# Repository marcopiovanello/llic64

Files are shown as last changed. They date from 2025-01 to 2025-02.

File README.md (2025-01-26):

Yet-Another-ControlPort-Converter for the Commodore C64



WIP!!

I'm developing yet another converter for Atari joystick based systems to USB.

What's different from other solutions?

Basically it's externally powered, which means that you can plug virtually anything and not think about drawing too much power from the system (e.g. the 100mA limit of the C64)

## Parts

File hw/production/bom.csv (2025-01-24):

Designator | Footprint | Quantity | Value | LCSC Part #
C1 | 0402 | 1 | 10n | C15195
C2 | 0603 | 1 | 100n | C14663
C200, C201, C204, C205, C206, C207, C208, C209, C210, C214, C300, C301, C302, C303, C304 | 0402 | 15 | 100n | C1525
C202, C203, C211 | 0402 | 3 | 1u | C52923
C215 | 0402 | 1 | 15p | C1548
C3 | 0603 | 1 | 1u | C15849
C4 | 0805 | 1 | 10u | C440198
D2 | D_SOD-323 | 1 | D_Schottky | C191023
D6, D7 | 0603 | 2 | RED | C2286
FB1 | 0805 | 1 | 100Ω@100MHz | C1015
J1 | USB_C_Receptacle_GCT_USB4125-xx-x_6P_TopMnt_Horizontal | 1 | USB_C_Receptacle_PowerOnly_6P | C456012
J100 | PinHeader_1x05_P2.54mm_Vertical | 1 | Conn_01x05_Pin
J2 | CONN_UJ2-AH-SMT_CUD | 1 | USB_A
J300 | DSUB-9_Female_EdgeMount_P2.77mm | 1 | DE9_Receptacle
R200, R201 | 0402 | 2 | 27R | C25092
R203, R6, R9 | 0402 | 3 | 1k | C11702
R204, R207 | 0402 | 2 | 10k
R7, R8 | 0402 | 2 | 5K1
SW1 | SW_SPST_B3U-1000P | 1 | SW_Push | C498294
U1 | Texas_DRT-3 | 1 | TPD2EUSB30 | C97502
U2 | WSON-6-1EP_2x2mm_P0.65mm_EP1x1.6mm_ThermalVias | 1 | TLV76733DRVx | C2848334
U200 | QFN-56-1EP_7x7mm_P0.4mm_EP3.2x3.2mm_ThermalVias | 1 | RP2040
U201 | Winbond_USON-8-1EP_3x2mm_P0.5mm_EP0.2x1.6mm | 1 | W25Q16JVUXIQ | C2843335
U300, U301, U302, U303, U304 | SOT-353_SC-70-5 | 5 | 74AHCT1G125
X100 | Crystal_SMD_2016-4Pin_2.0x1.6mm | 1 | ASE-12MHz | C669076

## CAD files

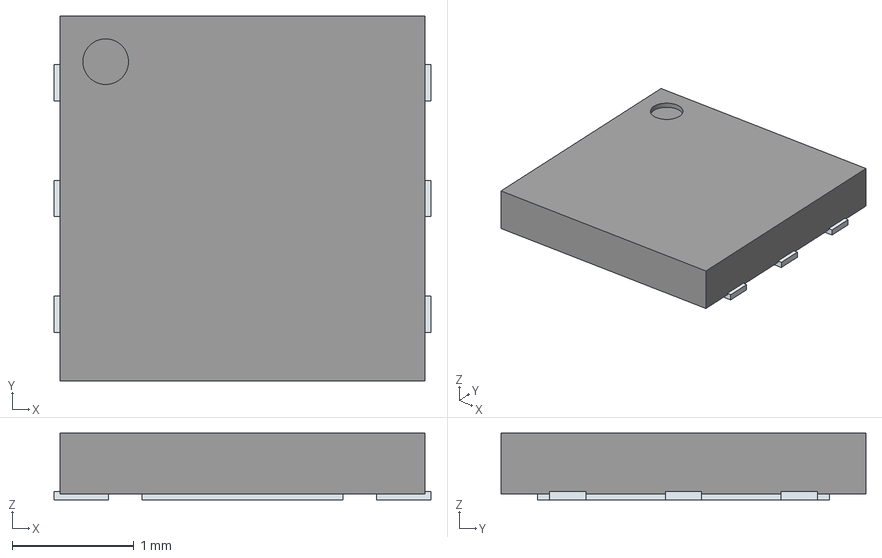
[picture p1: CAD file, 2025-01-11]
hw/NCP708MU330TAG/NCP708MU330TAG.stp
3.10 x 3.00 x 0.55 mm
ThermalPin
PinsArrayLR

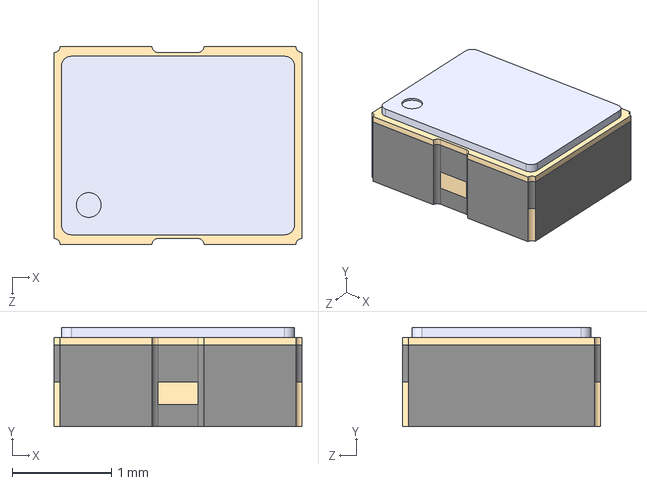
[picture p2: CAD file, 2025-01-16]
hw/OSC.STEP
2.50 x 1.00 x 2.00 mm

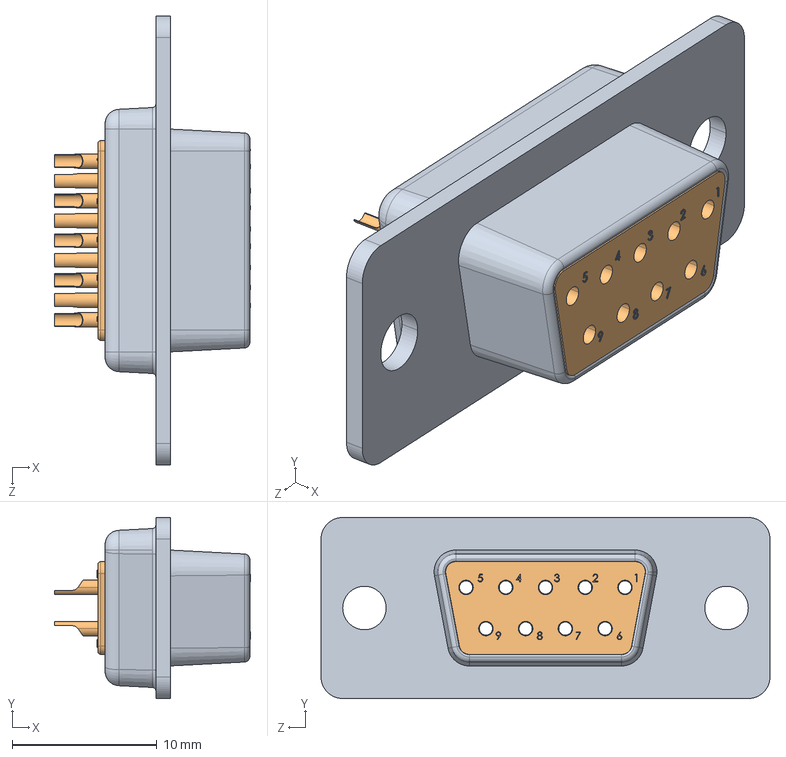
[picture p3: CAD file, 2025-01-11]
hw/DB9 female connector.STEP
13.5 x 12.5 x 31.0 mm

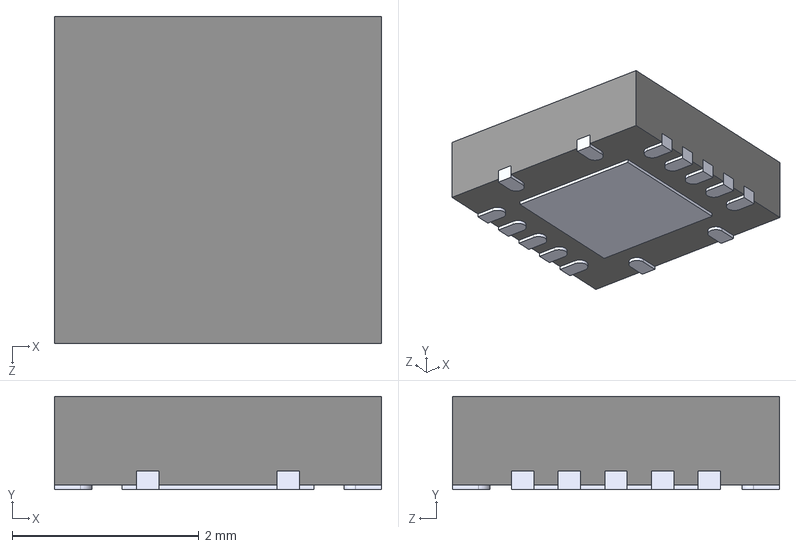
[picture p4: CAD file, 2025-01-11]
hw/SN74AHCT125RGYR.step
3.50 x 1.00 x 3.50 mm

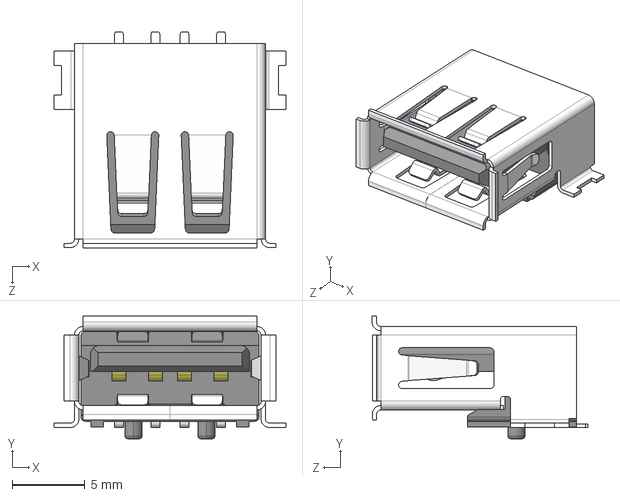
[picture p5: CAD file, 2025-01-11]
hw/UJ2-AH-4-SMT.step
15.9 x 8.40 x 14.8 mm

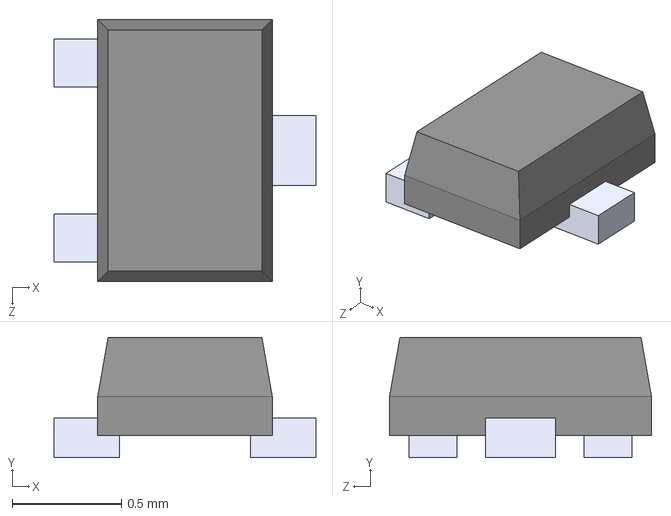
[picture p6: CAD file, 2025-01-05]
hw/SOT723.STEP
1.20 x 0.55 x 1.20 mm

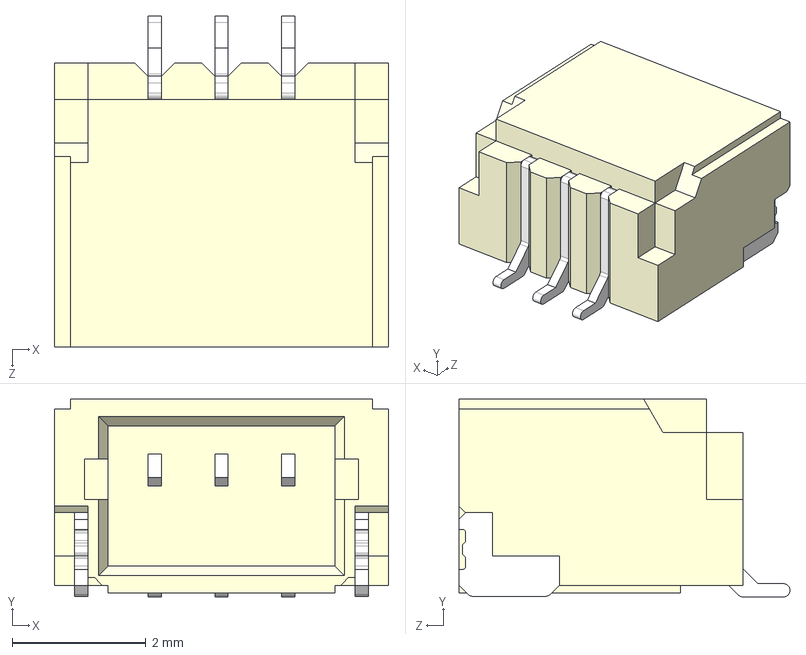
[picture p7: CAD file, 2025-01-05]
hw/SM03B-SRSS-TB(LF)(SN)--3DModel-STEP-56544.STEP
5.00 x 2.96 x 4.95 mm

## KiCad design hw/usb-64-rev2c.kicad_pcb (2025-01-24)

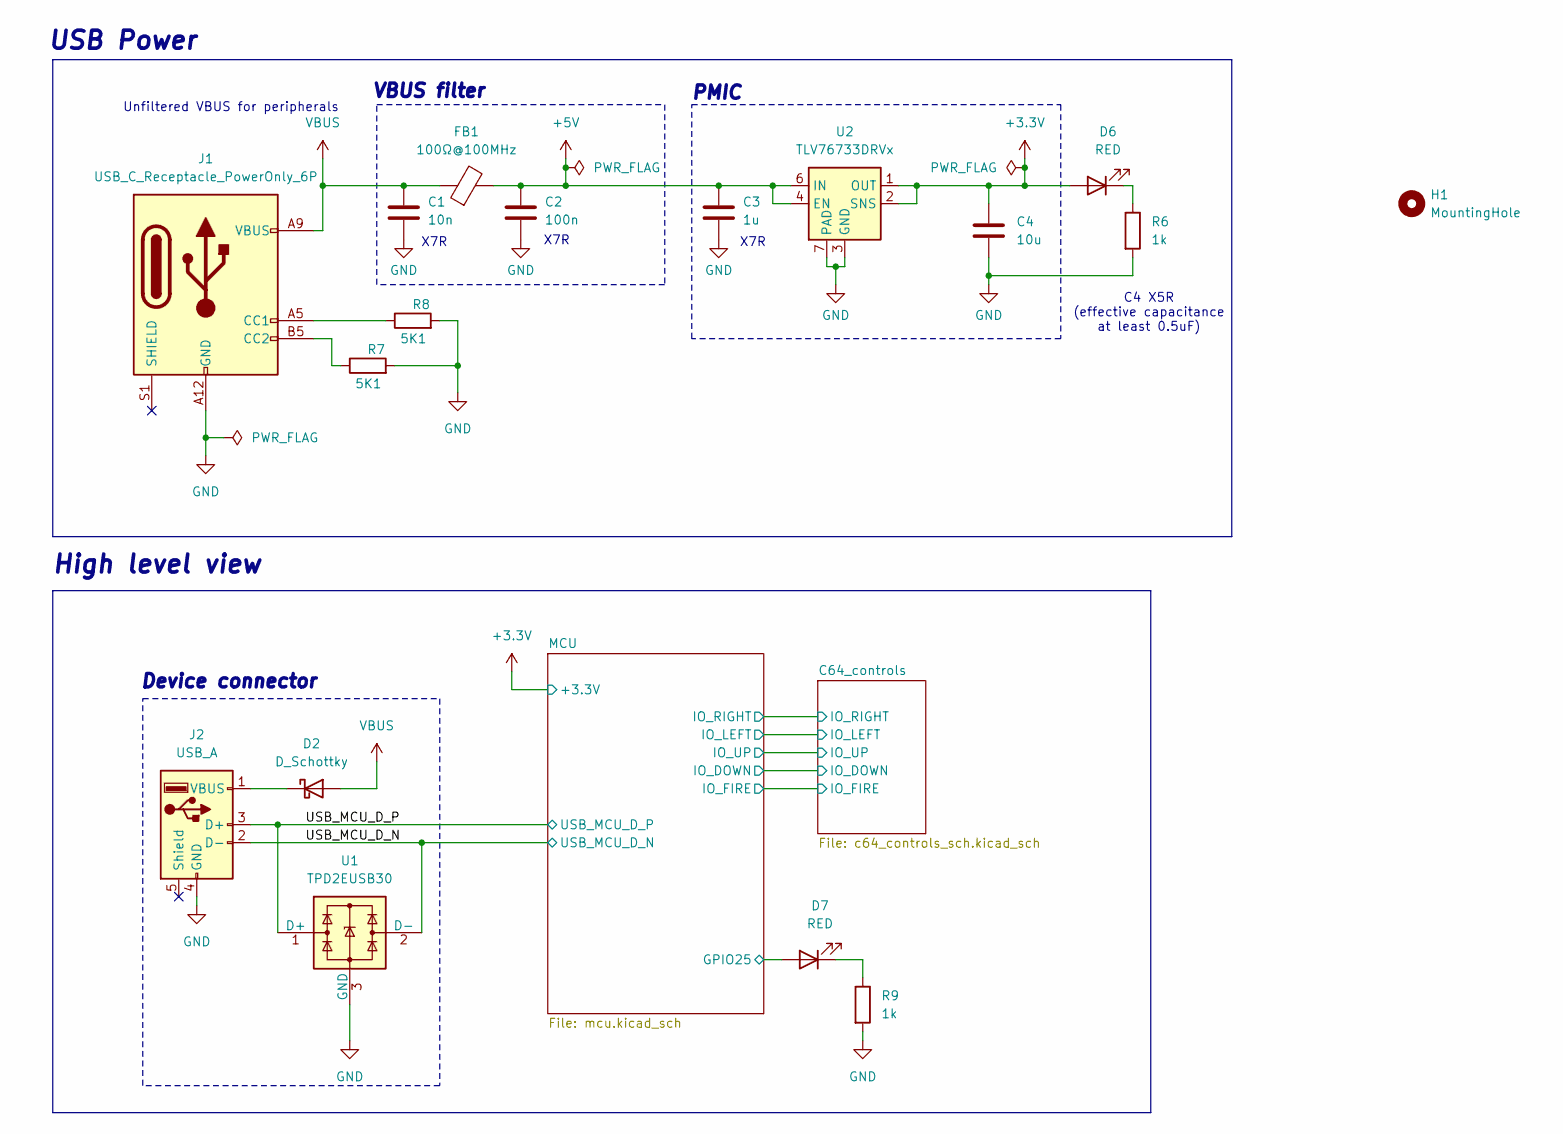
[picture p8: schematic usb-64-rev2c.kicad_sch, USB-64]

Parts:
C1: 10n; C_0402_1005Metric; LCSC Part # C15195
C2: 100n; C_0603_1608Metric; LCSC Part # C14663
C3: 1u; C_0603_1608Metric; LCSC Part # C15849
C4: 10u; C_0805_2012Metric; LCSC Part # C440198
D2: D_Schottky; D_SOD-323; LCSC Part # C191023
D6, D7: RED; LED_0603_1608Metric; LCSC Part # C2286
FB1: 100Ω@100MHz; L_0805_2012Metric; LCSC Part # C1015
H1: MountingHole; MountingHole_2.2mm_M2
J1: USB_C_Receptacle_PowerOnly_6P; USB_C_Receptacle_GCT_USB4125-xx-x_6P_TopMnt_Horizontal; LCSC Part # C456012
J2: USB_A; CONN_UJ2-AH-SMT_CUD
R6, R9: 1k; R_0402_1005Metric; LCSC Part # C11702
R7, R8: 5K1; R_0402_1005Metric
U1: TPD2EUSB30; Texas_DRT-3; LCSC Part # C97502
U2: TLV76733DRVx; WSON-6-1EP_2x2mm_P0.65mm_EP1x1.6mm_ThermalVias; LCSC Part # C2848334

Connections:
+3.3V: C4.1, D6.2 (A), U2.1 (OUT), U2.2 (SNS); also elsewhere on the board
+5V: C2.1, C3.1, FB1.2, U2.4 (EN), U2.6 (IN); also elsewhere on the board
/MCU/GPIO25: D7.2 (A); also elsewhere on the board
/USB_MCU_D_N: J2.2 (D-), U1.2 (D-); also elsewhere on the board
/USB_MCU_D_P: J2.3 (D+), U1.1 (D+); also elsewhere on the board
GND: C1.2, C2.2, C3.2, C4.2, J1.A12 (GND), J1.B12 (GND), J2.4 (GND), R6.2, R7.2, R8.2, R9.2, U1.3 (GND), U2.3 (GND), U2.5 (GND), U2.7 (PAD); also elsewhere on the board
unnamed: D2.1 (K), J2.1 (VBUS)
unnamed: D6.1 (K), R6.1
unnamed: D7.1 (K), R9.1
unnamed: J1.A5 (CC1), R8.1
unnamed: J1.B5 (CC2), R7.1
VBUS: C1.1, D2.2 (A), FB1.1, J1.A9 (VBUS), J1.B9 (VBUS)

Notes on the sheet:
PMIC
X7R
USB Power
X7R
High level view
Unfiltered VBUS for peripherals
C4 X5R (effective capacitance at least 0.5uF)
Device connector
VBUS filter

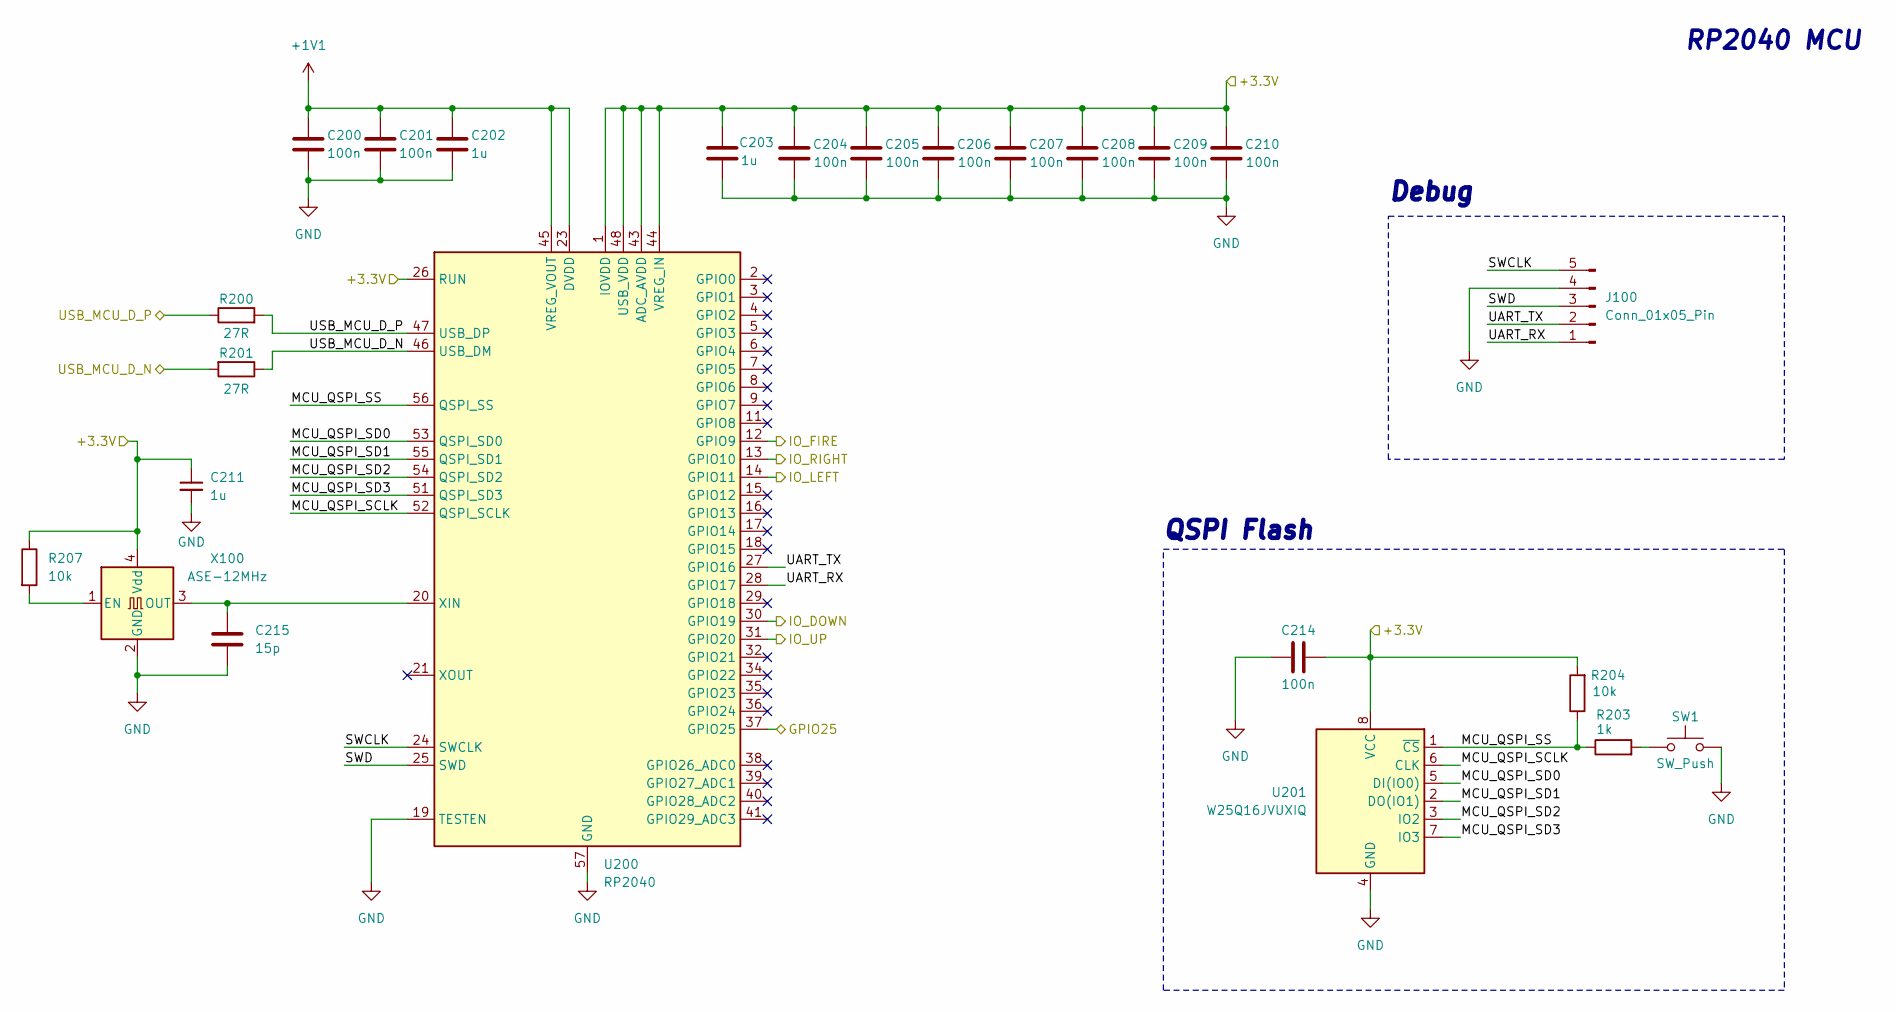
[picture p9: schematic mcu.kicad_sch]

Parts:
C200, C201, C204, C205, C206, C207, C208, C209, C210, C214: 100n; C_0402_1005Metric; LCSC Part # C1525
C202, C203, C211: 1u; C_0402_1005Metric; LCSC Part # C52923
C215: 15p; C_0402_1005Metric
J100: Conn_01x05_Pin; PinHeader_1x05_P2.54mm_Vertical
R200, R201: 27R; R_0402_1005Metric; LCSC Part # C25092
R203: 1k; R_0402_1005Metric; LCSC Part # C11702
R204, R207: 10k; R_0402_1005Metric
SW1: SW_Push; SW_SPST_B3U-1000P; LCSC Part # C498294
U200: RP2040; QFN-56-1EP_7x7mm_P0.4mm_EP3.2x3.2mm_ThermalVias
U201: W25Q16JVUXIQ; Winbond_USON-8-1EP_3x2mm_P0.5mm_EP0.2x1.6mm; LCSC Part # C2843335
X100: ASE-12MHz; Crystal_SMD_2016-4Pin_2.0x1.6mm; LCSC Part # C669076

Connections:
+1V1: C200.1, C201.1, C202.1, U200.23 (DVDD), U200.45 (VREG_VOUT), U200.50 (DVDD)
+3.3V: C203.1, C204.1, C205.1, C206.1, C207.1, C208.1, C209.1, C210.1, C211.1, C214.2, R204.2, R207.1, U200.1 (IOVDD), U200.10 (IOVDD), U200.22 (IOVDD), U200.26 (RUN), U200.33 (IOVDD), U200.42 (IOVDD), U200.43 (ADC_AVDD), U200.44 (VREG_IN), U200.48 (USB_VDD), U200.49 (IOVDD), U201.8 (VCC), X100.4 (Vdd); also elsewhere on the board
/C64_controls/IO_DOWN: U200.30 (GPIO19); also elsewhere on the board
/C64_controls/IO_FIRE: U200.12 (GPIO9); also elsewhere on the board
/C64_controls/IO_LEFT: U200.14 (GPIO11); also elsewhere on the board
/C64_controls/IO_RIGHT: U200.13 (GPIO10); also elsewhere on the board
/C64_controls/IO_UP: U200.31 (GPIO20); also elsewhere on the board
/MCU/GPIO25: U200.37 (GPIO25); also elsewhere on the board
/MCU/MCU_QSPI_SCLK: U200.52 (QSPI_SCLK), U201.6 (CLK)
/MCU/MCU_QSPI_SD0: U200.53 (QSPI_SD0), U201.5 (DI(IO0))
/MCU/MCU_QSPI_SD1: U200.55 (QSPI_SD1), U201.2 (DO(IO1))
/MCU/MCU_QSPI_SD2: U200.54 (QSPI_SD2), U201.3 (IO2)
/MCU/MCU_QSPI_SD3: U200.51 (QSPI_SD3), U201.7 (IO3)
/MCU/MCU_QSPI_SS: R203.1, R204.1, U200.56 (QSPI_SS), U201.1 (~CS)
/MCU/SWCLK: J100.5, U200.24 (SWCLK)
/MCU/SWD: J100.3, U200.25 (SWD)
/MCU/UART_RX: J100.1, U200.28 (GPIO17)
/MCU/UART_TX: J100.2, U200.27 (GPIO16)
/USB_MCU_D_N: R201.1, R201.2, U200.46 (USB_DM); also elsewhere on the board
/USB_MCU_D_P: R200.1, R200.2, U200.47 (USB_DP); also elsewhere on the board
GND: C200.2, C201.2, C202.2, C203.2, C204.2, C205.2, C206.2, C207.2, C208.2, C209.2, C210.2, C211.2, C214.1, C215.2, J100.4, SW1.2, U200.19 (TESTEN), U200.57 (GND), U201.4 (GND), X100.2 (GND); also elsewhere on the board
unnamed: R203.2, SW1.1
unnamed: C215.1, U200.20 (XIN), X100.3 (OUT)
unnamed: R207.2, X100.1 (EN)

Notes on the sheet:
Debug
RP2040 MCU
QSPI Flash

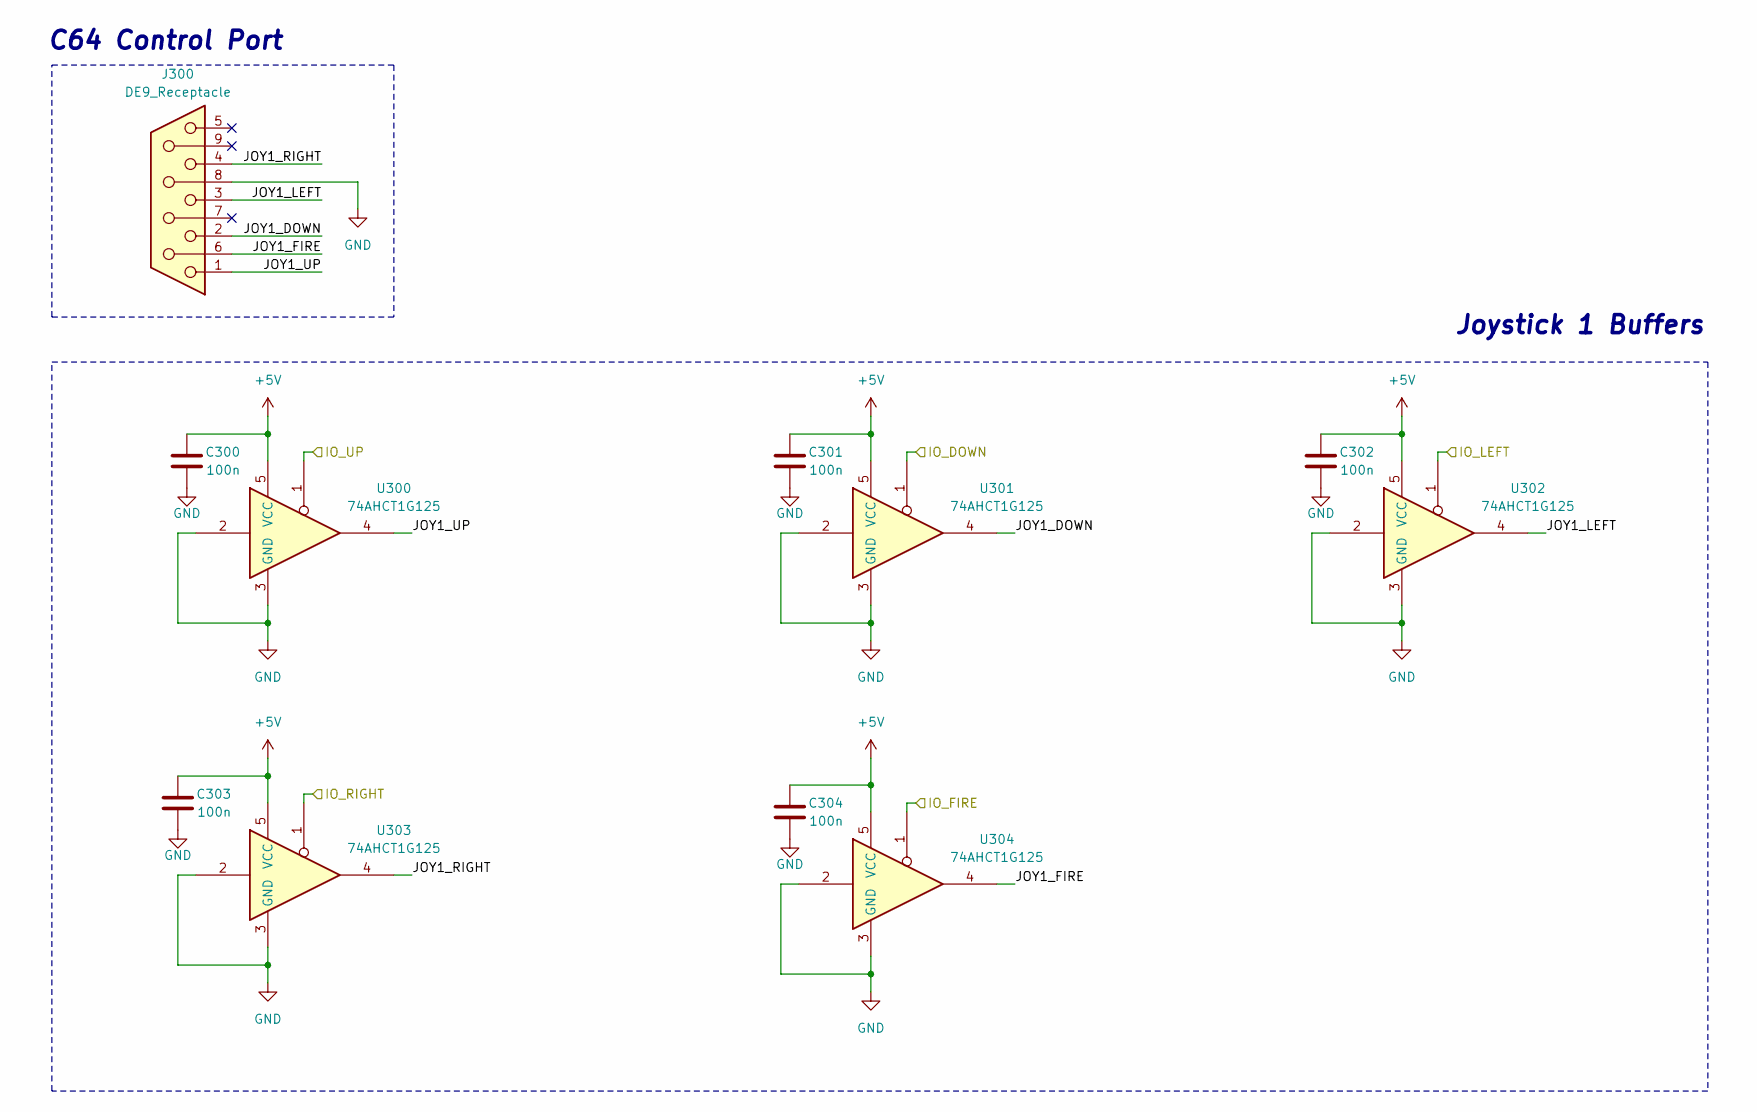
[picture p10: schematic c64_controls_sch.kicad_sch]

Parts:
C300, C301, C302, C303, C304: 100n; C_0402_1005Metric; LCSC Part # C1525
J300: DE9_Receptacle; DSUB-9_Female_EdgeMount_P2.77mm
U300, U301, U302, U303, U304: 74AHCT1G125; SOT-353_SC-70-5

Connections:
+5V: C300.1, C301.1, C302.1, C303.1, C304.1, U300.5 (VCC), U301.5 (VCC), U302.5 (VCC), U303.5 (VCC), U304.5 (VCC); also elsewhere on the board
/C64_controls/IO_DOWN: U301.1; also elsewhere on the board
/C64_controls/IO_FIRE: U304.1; also elsewhere on the board
/C64_controls/IO_LEFT: U302.1; also elsewhere on the board
/C64_controls/IO_RIGHT: U303.1; also elsewhere on the board
/C64_controls/IO_UP: U300.1; also elsewhere on the board
/C64_controls/JOY1_DOWN: J300.2, U301.4
/C64_controls/JOY1_FIRE: J300.6, U304.4
/C64_controls/JOY1_LEFT: J300.3, U302.4
/C64_controls/JOY1_RIGHT: J300.4, U303.4
/C64_controls/JOY1_UP: J300.1, U300.4
GND: C300.2, C301.2, C302.2, C303.2, C304.2, J300.8, U300.2, U300.3 (GND), U301.2, U301.3 (GND), U302.2, U302.3 (GND), U303.2, U303.3 (GND), U304.2, U304.3 (GND); also elsewhere on the board

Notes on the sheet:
C64 Control Port
Joystick 1 Buffers

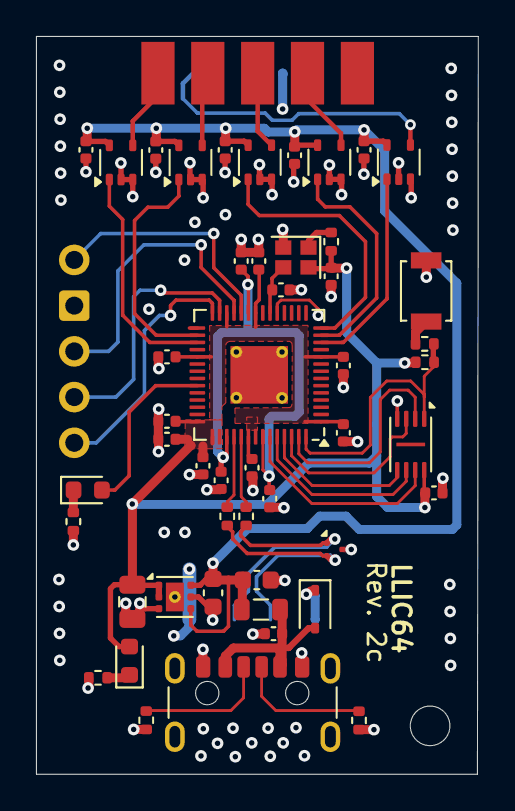
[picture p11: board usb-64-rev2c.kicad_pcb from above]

Board: 4 copper layers, 24.5 x 41.0 mm, 52 parts (1 on the bottom side), 36 nets.

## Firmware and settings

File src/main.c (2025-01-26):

#include <stdio.h>

#include "tusb.h"


#include "board_layout.h"
#include "board_output.h"

#include "pico/stdlib.h"
#include "pico/multicore.h"

const uint LED_PIN = 25;

void led_blinking_task(void);

extern void hid_app_task(void);

int main(void)
{
  board_output_init();
  stdio_uart_init();

  multicore_launch_core1(led_blinking_task);

  tusb_init();

  while (1)
  {
    tuh_task();
    hid_app_task();
  }

  return 0;
}

// System-good task
// Blink every second to signal that the board has not crashed
void led_blinking_task(void)
{
  gpio_init(LED_PIN);
  gpio_set_dir(LED_PIN, GPIO_OUT);
  while (1) 
  {
    gpio_put(LED_PIN, 0);
    sleep_ms(1000);
    gpio_put(LED_PIN, 1);
    sleep_ms(500);
  }
}

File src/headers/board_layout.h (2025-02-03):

// ---------------------------------------------+
// MACRO GPIO pin number
// Using Raspberry Pi Pico board pin enumeration
// ---------------------------------------------+

#define FIRE_BTN 9
#define JUMP_BTN 20

// directionals
#define UP_PIN 20
#define DOWN_PIN 19
#define RIGHT_PIN 10
#define LEFT_PIN 11

// shorthands for logic levels
#define HIGH 1
#define LOW 0

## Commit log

2025-01-05 changed pcb specs
    [usb-64-rev2c.kicad_pcb, usb-64-rev2c.kicad_sch, usb_sch.kicad_sch]
2025-01-06 pre production
    [bom.csv, designators.csv, positions.csv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]
2025-01-11 1p version
    [DB9 female connector.STEP, NCP708MU330TAG.stp, SN74AHCT125RGYR.step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]
2025-01-11 added 15pf load capacitor for oscillator
    [mcu.kicad_sch, usb-64-rev2c.kicad_pcb]
2025-01-16 pre production review
    [ASE-50.000MHZ-ET.STEP, OSC.STEP, W25Q32JVSSIQ--3DModel-STEP-269445.STEP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]
